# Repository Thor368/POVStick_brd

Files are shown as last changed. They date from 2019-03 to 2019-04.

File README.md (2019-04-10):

POVStick

This is a Persistance Of Vision display in form of a NeoPixel stick. In the future this will be a much shorter and denser handheld LED strip. A SLR will be used in long time exposure mode to "stitch" the image back together as the stick is moved across its field of vision.

The image is stored on a SD card and read by an AVR. The display itself is a string of WS2812 Pixel LEDs. At this (unoptimized) state the AVR is capable of displaying around 75 lines per second at 288 LEDs per line.

Current state: https://youtu.be/oT6iY_f27Is

# Board
The current relase V1.0 is currently in production. The board dimensions are 73x19mm² and feautre:
- ATmega1284 (8kB RAM) @12MHz
- microSD slot
- sleep mode (LED throw-off)
- 4 button inputs
- I²C for small OLED displays
- max. 18V input voltage

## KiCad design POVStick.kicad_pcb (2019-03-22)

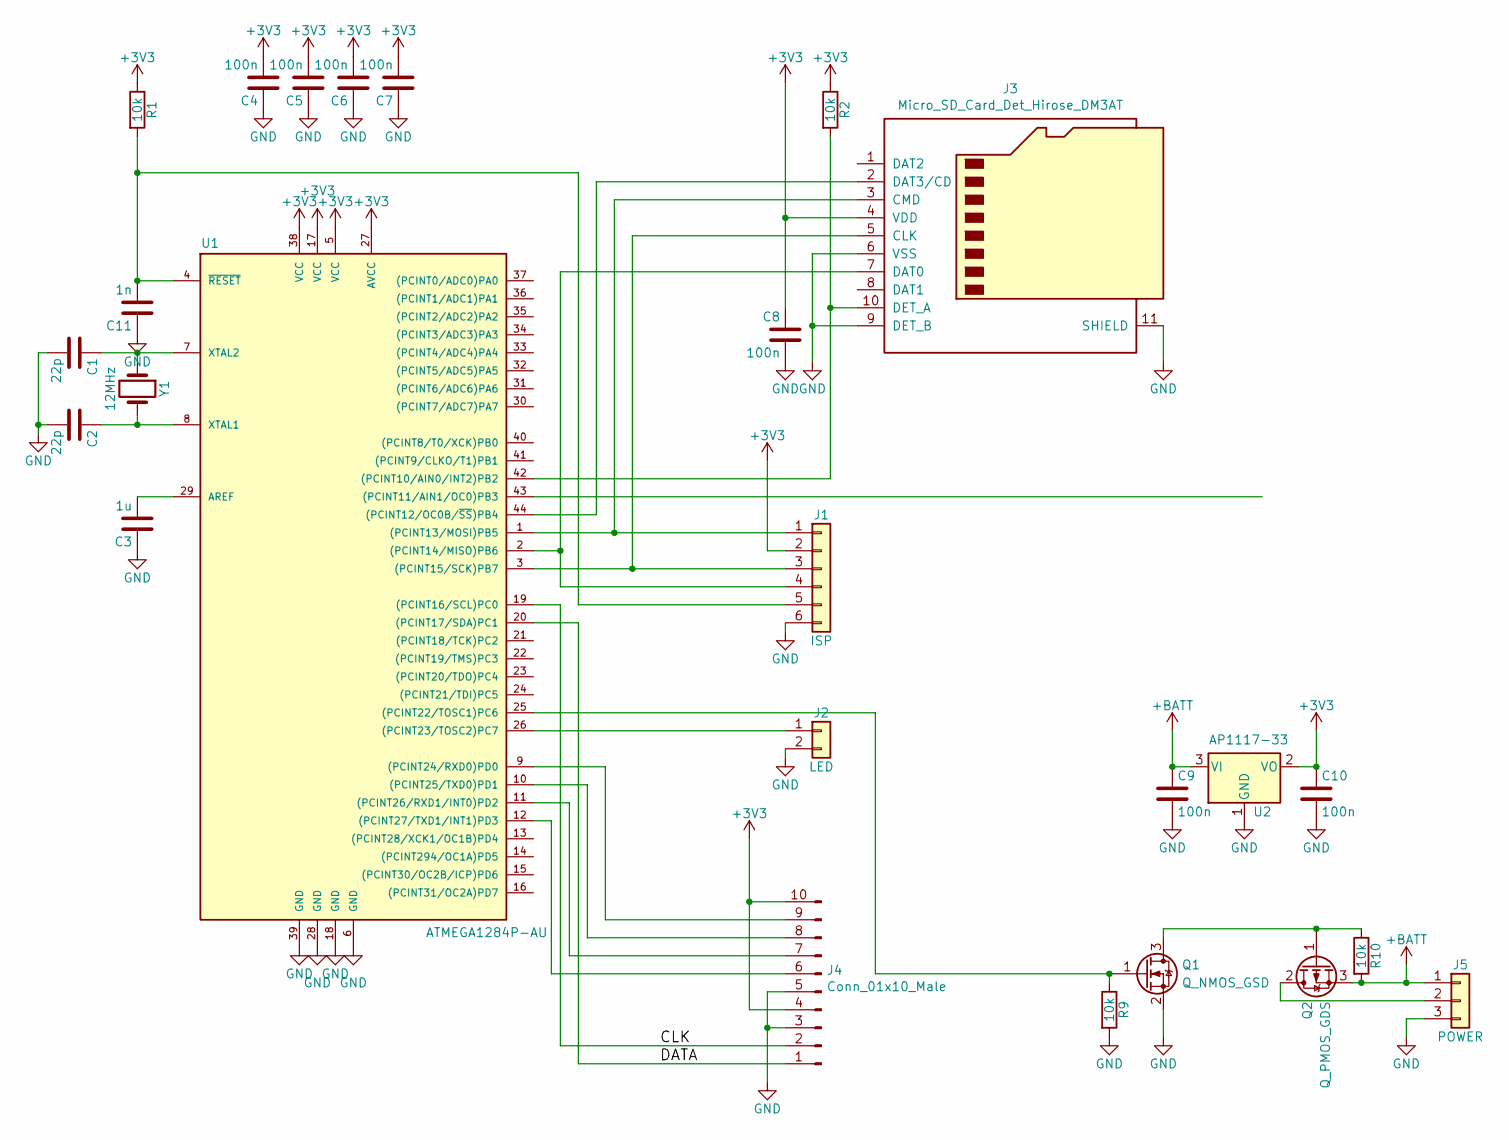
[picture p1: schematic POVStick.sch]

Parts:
C1, C2: 22p; C_0805_2012Metric
C3: 1u; C_0805_2012Metric
C4, C5, C6, C7, C8, C9, C10: 100n; C_0805_2012Metric
C11: 1n; C_0805_2012Metric
J1: ISP; PinHeader_2x03_P2.54mm_Vertical
J2: LED; PinHeader_1x02_P2.54mm_Vertical
J3: Micro_SD_Card_Det_Hirose_DM3AT; microSD_HC_Hirose_DM3D-SF
J4: Conn_01x10_Male; PinSocket_1x10_P2.54mm_Vertical
J5: POWER; TerminalBlock_bornier-3_P5.08mm
Q1: Q_NMOS_GSD; SOT-23
Q2: Q_PMOS_GDS; TO-252-2
R1, R2, R9, R10: 10k; R_0805_2012Metric
U1: ATMEGA1284P-AU; LQFP-44_10x10mm_P0.8mm
U2: AP1117-33; SOT-223-3_TabPin2
Y1: 12MHz; Crystal_HC49-U_Vertical

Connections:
+3V3: C4.2, C5.2, C6.2, C7.2, C8.1, C10.1, J1.2, J3.4 (VDD), J4.4, J4.10, R1.1, R2.1, U1.5 (VCC), U1.17 (VCC), U1.27 (AVCC), U1.38 (VCC), U2.2 (VO)
+BATT: C9.1, J5.1, Q2.3 (S), R10.2, U2.3 (VI)
/CLK: J4.2, U1.19 ((PCINT16/SCL)PC0)
/DATA: J4.1, U1.20 ((PCINT17/SDA)PC1)
GND: C1.2, C2.2, C3.1, C4.1, C5.1, C6.1, C7.1, C8.2, C9.2, C10.2, C11.1, J1.6, J2.2, J3.6 (VSS), J3.9 (DET_B), J3.11 (SHIELD), J4.3, J4.5, J5.3, Q1.2 (S), R9.2, U1.6 (GND), U1.18 (GND), U1.28 (GND), U1.39 (GND), U2.1 (GND)
unnamed: C1.1, U1.7 (XTAL2), Y1.1
unnamed: C2.1, U1.8 (XTAL1), Y1.2
unnamed: C3.2, U1.29 (AREF)
unnamed: C11.2, J1.5, R1.2, U1.4 (~RESET)
unnamed: J1.1, J3.3 (CMD), U1.1 ((PCINT13/MOSI)PB5)
unnamed: J1.3, J3.5 (CLK), U1.3 ((PCINT15/SCK)PB7)
unnamed: J1.4, J3.7 (DAT0), U1.2 ((PCINT14/MISO)PB6)
unnamed: J2.1, U1.26 ((PCINT23/TOSC2)PC7)
unnamed: J3.2 (DAT3/CD), U1.44 ((PCINT12/OC0B/~SS~)PB4)
unnamed: J3.10 (DET_A), R2.2, U1.42 ((PCINT10/AIN0/INT2)PB2)
unnamed: J4.6, U1.12 ((PCINT27/TXD1/INT1)PD3)
unnamed: J4.7, U1.11 ((PCINT26/RXD1/INT0)PD2)
unnamed: J4.8, U1.10 ((PCINT25/TXD0)PD1)
unnamed: J4.9, U1.9 ((PCINT24/RXD0)PD0)
unnamed: J5.2, Q2.2 (D)
unnamed: Q1.1 (G), R9.1, U1.25 ((PCINT22/TOSC1)PC6)
unnamed: Q1.3 (D), Q2.1 (G), R10.1

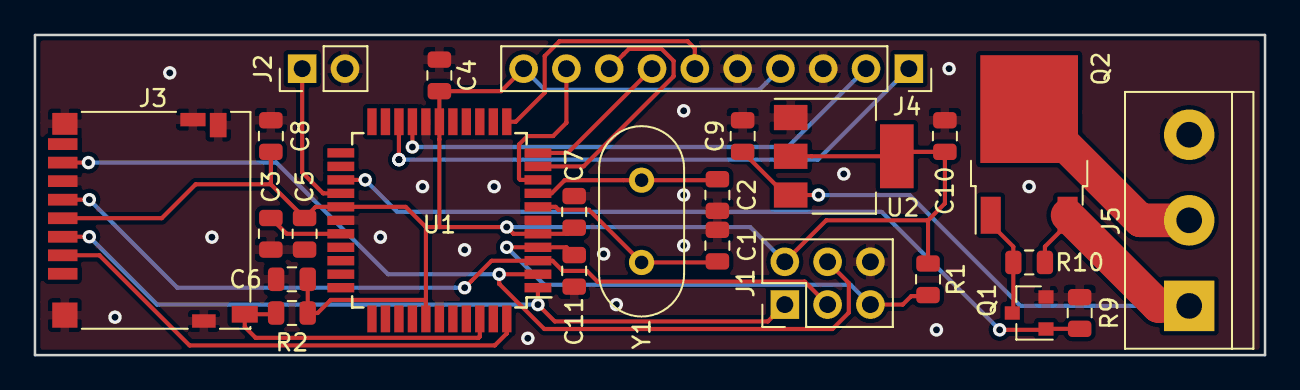
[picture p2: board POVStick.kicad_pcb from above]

Board: 2 copper layers, 73.0 x 19.0 mm, 25 parts (0 on the bottom side), 22 nets.

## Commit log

2018-01-03 - added a description in README.md - schematic is pretty much complete - footprints are mostly selected - missing a footprint for a micro sd card slot, tho -> problem for future thor
    [POVStick.kicad_pcb, POVStick.sch]
2018-06-28 - changed design over to UI connector instead of dedicated keys and OLED - added power fet to switch Vbat for LEDs - added 3V3 reg
    [POVStick.sch]
2019-03-21 - changed SD socket - removed pull-ups - changed pinout of IO jack - routed the layout
    [POVStick.sch]
2019-03-22 - added home point - added GEBERBER to .gitignore - moved a REF - base for V1.0
    [POVStick.kicad_pcb]
2019-04-10 - added max input voltage to readme
